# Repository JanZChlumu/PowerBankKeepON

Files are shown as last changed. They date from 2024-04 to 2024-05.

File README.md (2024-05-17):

# Keep powerbank on

>This project is based on ideas from [Andreas Spiess YouTube video ](https://www.youtube.com/watch?v=SgV6_Y_sg4k&t=782s&ab_channel=AndreasSpiess)

The main idea is to keep powerbank on if her load is less than powerbank on threshold.
Every powerbank detect drawn current if current is less than cca 5mA the powebank enable timeout for switch off.
The tool is trying to catch the maximum power off timeout and connect some load before timeout. It will postpone (reset) automatic power off.

Example with load connection:
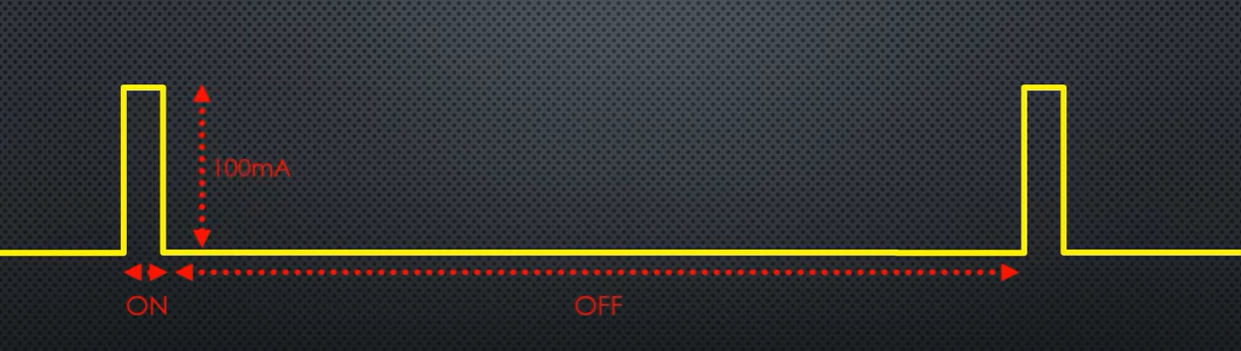
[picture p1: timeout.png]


## PCB
Was designed in KiCad... see folder [folder](PCB)
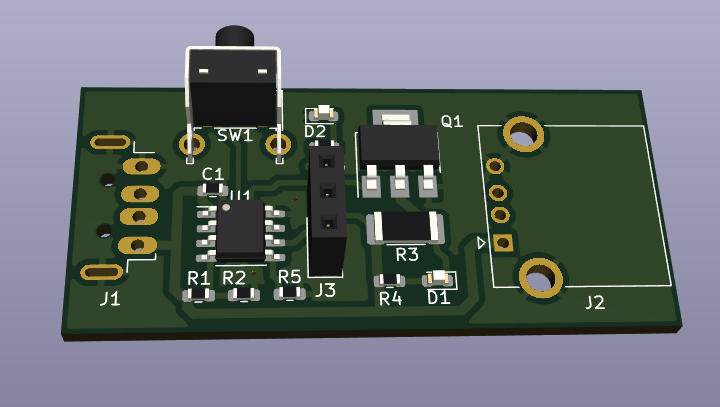
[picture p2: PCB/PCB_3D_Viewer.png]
PCB_3D Viewer.png


## How to use the tool
1. **Learning mode**
<br> press the button and connect powerbank. The GREEN led will blink 3times that means the powerbank is in learning mode. The tool is waiting until the powerbank will be automatically powered off. This time is stored in internal eeprom.
2. **Working mode**  
<br>switch on or Reconnect the powerbank. If tool correctly stored a power off time in step one and this time is bigger than 1 second, the GREEN led will be ON for 5 seconds.
<br> If learning process failed, the GREEN and RED leds blinks 3 times and tool is automatically switched to 1st point - learning mode.

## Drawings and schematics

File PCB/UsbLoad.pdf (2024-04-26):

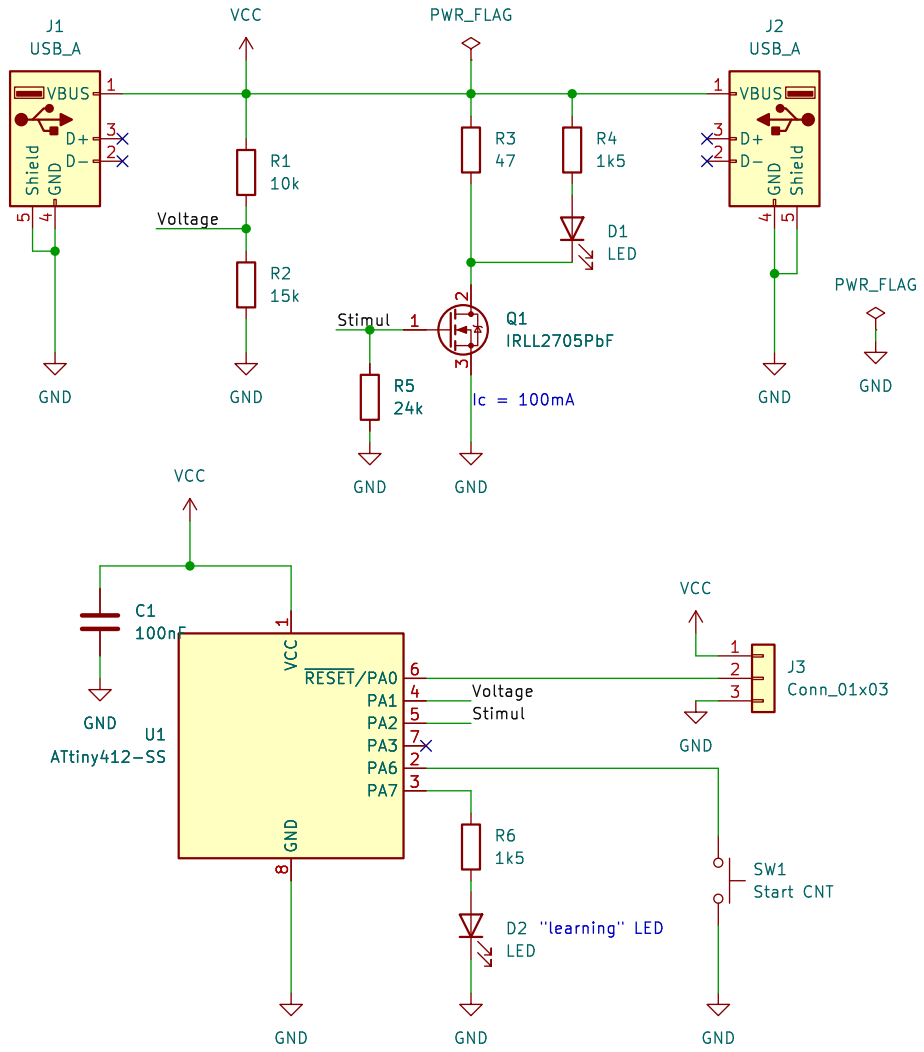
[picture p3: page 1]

Id: 1/1 Title: File: UsbLoad.kicad_sch Sheet: /

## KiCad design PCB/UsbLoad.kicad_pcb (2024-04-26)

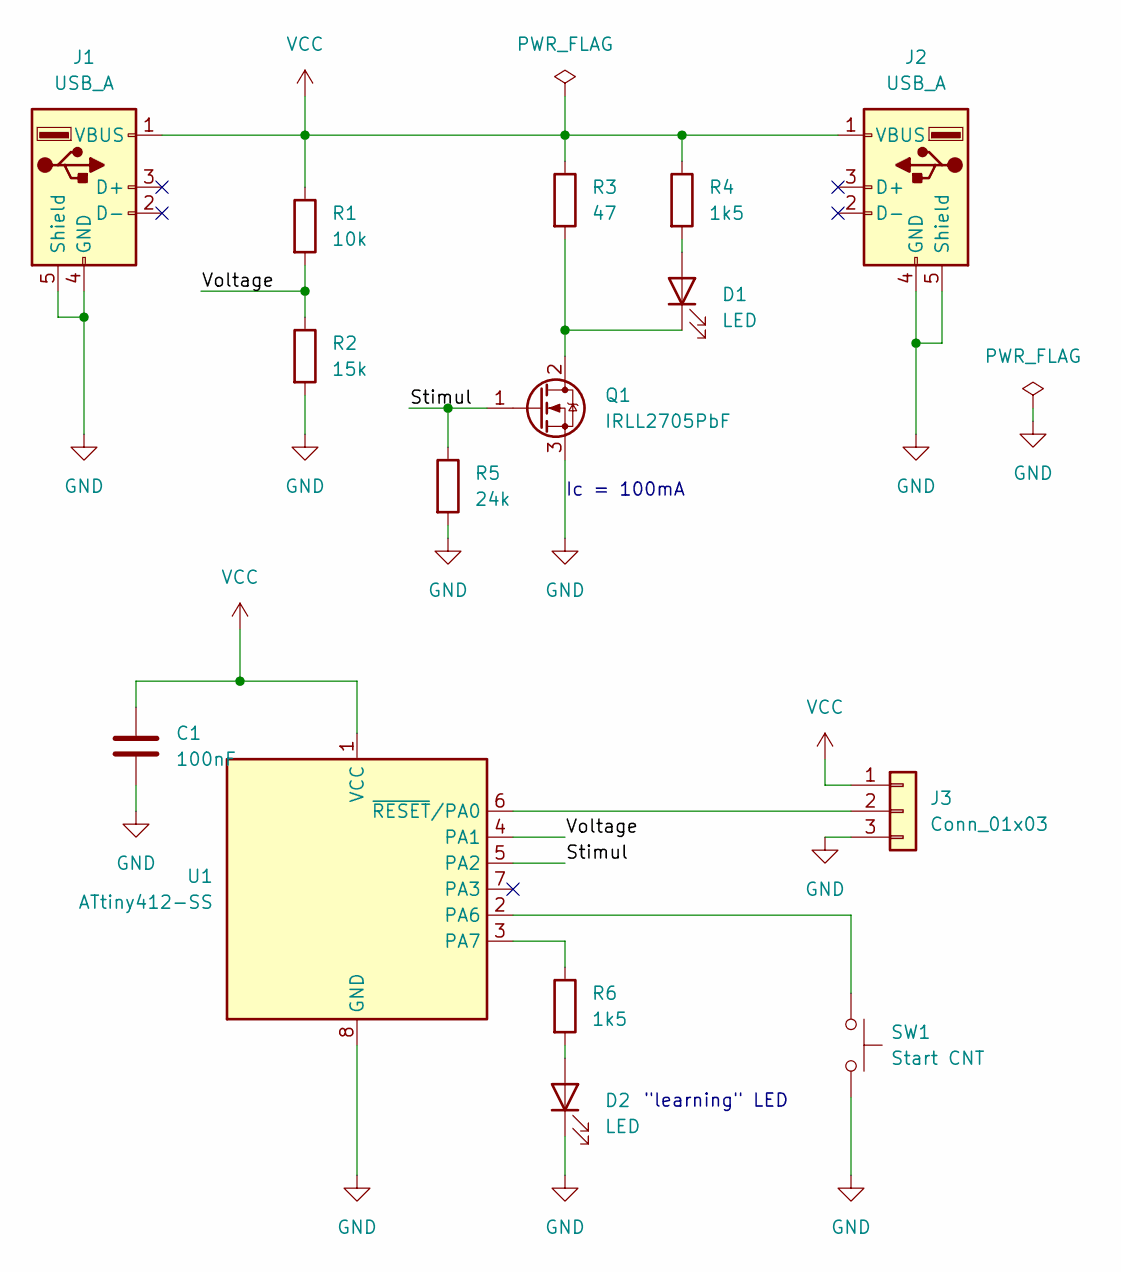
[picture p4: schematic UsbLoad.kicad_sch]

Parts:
C1: 100nF; R_0603_1608Metric
D1, D2: LED; LED_0603_1608Metric
J1: USB_A; USB_A_Molex_18161_Horizontal
J2: USB_A; USB_A_CONNFLY_DS1095-WNR0
J3: Conn_01x03; PinSocket_1x03_P2.54mm_Vertical
Q1: IRLL2705PbF; SOT-223-3_TabPin2
R1: 10k; R_0603_1608Metric
R2: 15k; R_0603_1608Metric
R3: 47; R_2010_5025Metric_Pad1.40x2.65mm_HandSolder
R4, R6: 1k5; R_0603_1608Metric
R5: 24k; R_0603_1608Metric
SW1: Start CNT; SW_Tactile_SPST_Angled_PTS645Vx58-2LFS
U1: ATtiny412-SS; SOIC-8_3.9x4.9mm_P1.27mm

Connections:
/Stimul: Q1.1 (G), R5.1, U1.5 (PA2)
/Voltage: R1.2, R2.1, U1.4 (PA1)
GND: C1.1, D2.1 (K), J1.4 (GND), J1.5 (Shield), J2.4 (GND), J2.5 (Shield), J3.3, Q1.3 (S), R2.2, R5.2, SW1.2, U1.8 (GND)
unnamed: D1.2 (A), R4.2
unnamed: D1.1 (K), Q1.2 (D), R3.2
unnamed: D2.2 (A), R6.2
unnamed: J3.2, U1.6 (~RESET/PA0)
unnamed: SW1.1, U1.2 (PA6)
unnamed: R6.1, U1.3 (PA7)
VCC: C1.2, J1.1 (VBUS), J2.1 (VBUS), J3.1, R1.1, R3.1, R4.1, U1.1 (VCC)

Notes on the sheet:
"learning" LED
Ic = 100mA

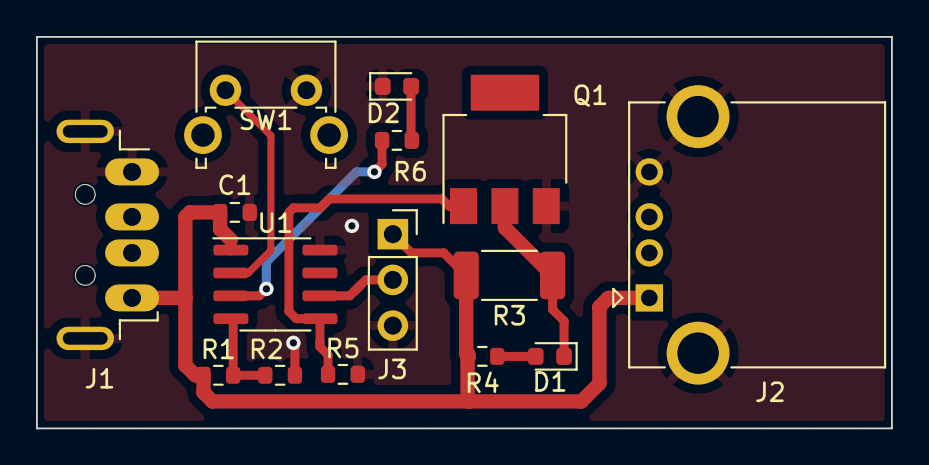
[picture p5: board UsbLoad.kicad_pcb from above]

Board: 2 copper layers, 47.5 x 21.8 mm, 15 parts (0 on the bottom side), 10 nets.

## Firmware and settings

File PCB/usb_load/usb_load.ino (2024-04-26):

#include <EEPROM.h>

#define PIN_BTN PIN_PA6
#define PIN_VOLTAGE PIN_PA1
#define PIN_STIMUL PA2

static unsigned int tick = 0;
static bool store;
unsigned int addr = 0;

void setup() {
  pinMode(PIN_BTN, INPUT_PULLUP);

  if(digitalRead(PIN_BTN) == LOW)
  {
    //button pressed start counting
    store = true;
    EEPROM.put(addr, tick);
  }
  else
  {
    store = false;
  }

}

void loop() {
  // put your main code here, to run repeatedly:
  EEPROM.write(addr, tick);
  delay(1000);
}

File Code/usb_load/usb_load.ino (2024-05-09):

#include <EEPROM.h>

#define PIN_BTN PIN_PA6         // learning button
#define PIN_VOLTAGE PIN_PA1     // voltage measurement
#define PIN_FET PIN_PA2         // FET transistor Gate
#define PIN_LED_GREEN PIN_PA7   // learning Green LED
#define MIN_TRIGGER_TIME_MS 20  // minimal time when FET is OPEN

static unsigned int tick = 0;
static bool learning;
unsigned int addr = 0;
unsigned int sleepTime_ms = 0;

void setup() {
  pinMode(PIN_BTN, INPUT_PULLUP);

  pinMode(PIN_LED_GREEN, OUTPUT);
  digitalWrite(PIN_LED_GREEN, LOW);

  pinMode(PIN_FET, OUTPUT);
  digitalWrite(PIN_FET, LOW);

  // Learning mode activated
  if (digitalRead(PIN_BTN) == LOW) {
    //button pressed start learning
    learning = true;

    // blink with Green learning LED
    for (char i = 0; i < 3; i++) {
      digitalWrite(PIN_LED_GREEN, HIGH);
      delay(100);
      digitalWrite(PIN_LED_GREEN, LOW);
    }
  } else
  // counting mode activated
  {
    learning = false;
    EEPROM.get(addr, tick);

    if (tick < 2) {
      learning = true;

      // probably error blink with both LEDs
      for (char i = 0; i < 3; i++) {
        digitalWrite(PIN_FET, HIGH);
        digitalWrite(PIN_LED_GREEN, HIGH);
        delay(100);
        digitalWrite(PIN_FET, LOW);
        digitalWrite(PIN_LED_GREEN, LOW);
      }
    } else {
      // expected that powerbank died before string the last value
      tick--;
      sleepTime_ms = tick * 1000;
    }
  }

  if (learning == true) {
    // reset tick stored in eeprom
    tick = 0;
    EEPROM.put(addr, tick);
  }
}

void loop() {

  // put your main code here, to run repeatedly:
  if (learning == true) {
    delay(1000);

    tick++;  // increment ticks
    EEPROM.put(addr, tick);
  }
  // trigger the FET every maximum timeout
  else {
    digitalWrite(PIN_FET, HIGH);
    delay(MIN_TRIGGER_TIME_MS);
    digitalWrite(PIN_FET, LOW);

    delay(sleepTime_ms);
  }
}

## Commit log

2024-04-26 PCB design
    [UsbLoad-B_Cu.gbr, UsbLoad-B_Mask.gbr, UsbLoad-B_Paste.gbr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]
2024-05-16 Rename PCB_3D Viewer.png to PCB_3D_Viewer.png
